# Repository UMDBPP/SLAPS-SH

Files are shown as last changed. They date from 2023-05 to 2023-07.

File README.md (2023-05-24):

# SLAPS-SH
The SLAPS Solar Harvester is intended as a the first step into solar power collection and management. While previous iterations in the SLAPS family have focused on solar panel deployment and configuration, the solar harvester focuses on collecting and managing the power generated by four solar panels. The primary device enabling this functionality is the AEM10941. This power harvesting IC collects power from the panels, regulates the power to multiple useful voltage levels, and charges a storage unit. This design required minimal passive components allowing for a low cost and space efficient design. In addition to the power harvesting circuit, the solar harvester will also feature a RP2040 microcontroller, altitude rated pressure-temperature sensor, and NAND flash for data logging. These additional components will provide an adequate test for the harvester capabilities. In order to leverage the space efficient nature of the electrical configuration, the structural construction of the solar harvester focuses on tight tolerances using 3D printed components. Maximizing the space efficiency of the solar harvester improves aesthetics and maximizes the flight line configurations that the solar harvester can fly on. Overall, this design will provide a realistic and maximally space efficient test of a solar harvesting circuit that could potentially be used in future SLAPS iterations.

## Electrical Overview
### AEM10941
The AEM10941 features multiple preset configurations as well as a custom mode. In this design, the configuration profile `111` is used by pulling the three configuration pins high. This configuration is designed for use with a Li-ion battery as the storage source and 3.3V and 1.8V outputs. The decision to use a Li-ion battery primarily comes from the need for a 3.3V output.

Quiescent current is expected to be roughly [0.6 \ \mu A](tex://0.6 \ \mu A) at a battery voltage of roughly 3.6V. The efficiency of the linear drop-out regulators are as follows:
- High-voltage: 80-90%
- Low-voltage: 70-80%

Overall, the losses experienced in the AEM10941 are relatively low in comparison to the power consumption of the device as a whole.

### RP2040
The RP2040 microcontroller is an incredibly popular Arduino compatible microcontroller with excellent design resources.

### MS560702BA03-50
The MS560702BA03-50 barometric pressure and temperature sensor designed to operate from [10](tex://10) to [1200 \ mbar](tex://1200 \ mbar) and [-40](tex://-40) to [85 \ \degree C](tex://85 \ \degree C). These values fall within typical launch conditions and this sensor should be able to provide barometric pressure and temperature values accurate to [\pm 2.5 mbar](tex://\pm 2.5 mbar) and [\pm 0.5 \ \degree C](tex://\pm 0.5 \ \degree C) for the duration of flight.

At a 3.3V supply voltage the MS560702BA03-50 has a peak power consumption of [4.62 \ mW](tex://4.62 \ mW) and a standby power consumption of [0.07 \ \mu W](tex://0.07 \ \mu W). Peak power consumption is unlikely to occur and typical power consumption at 1 sample/sec is expected to be less than [42 \ \mu W](tex://42 \ \mu W).

### Energy Storage
The solar harvester features one energy storage unit in the form of a single Li-ion battery cell.

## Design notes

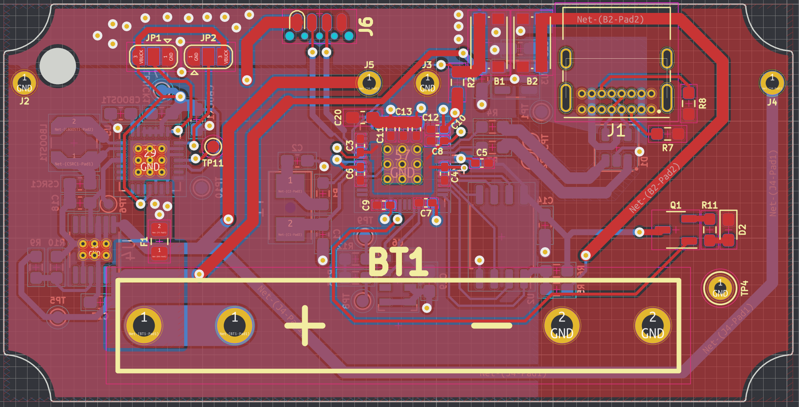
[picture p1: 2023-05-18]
Kicad/Screenshot 2023-05-16 at 6.40.45 PM.png

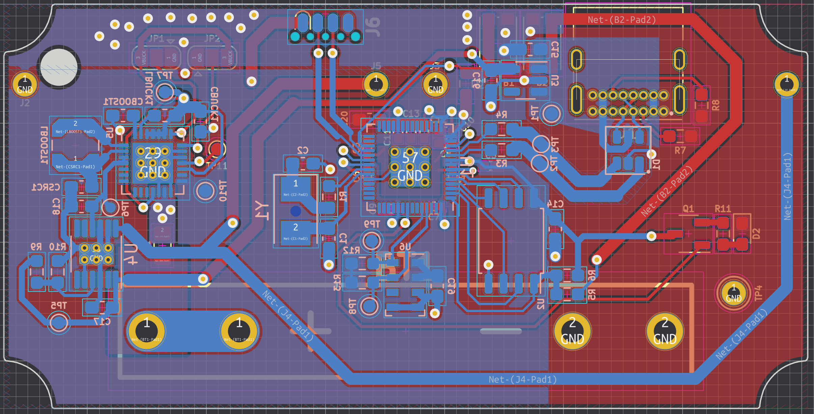
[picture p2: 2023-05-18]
Kicad/Screenshot 2023-05-16 at 6.40.51 PM.png

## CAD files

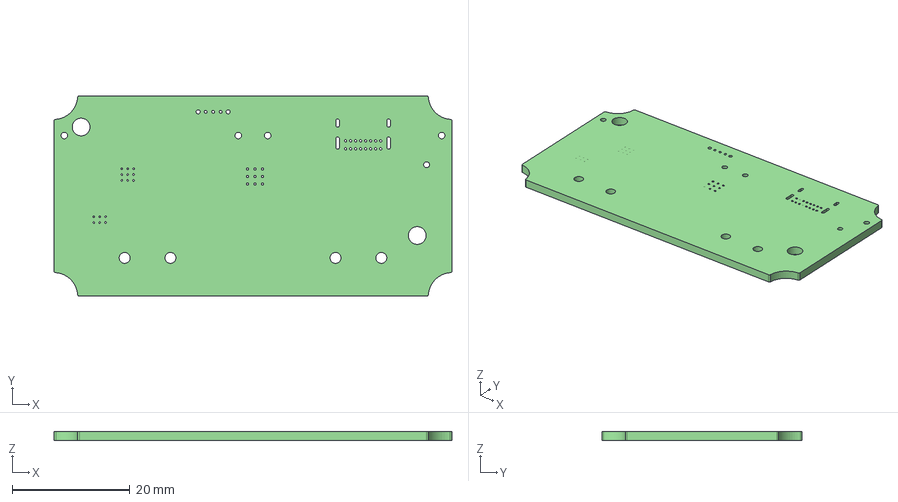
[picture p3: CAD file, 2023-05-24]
Kicad/SLAPS_Solar_Harvester/SLAPS_Solar_Harvester.step
67.5 x 34.0 x 1.60 mm

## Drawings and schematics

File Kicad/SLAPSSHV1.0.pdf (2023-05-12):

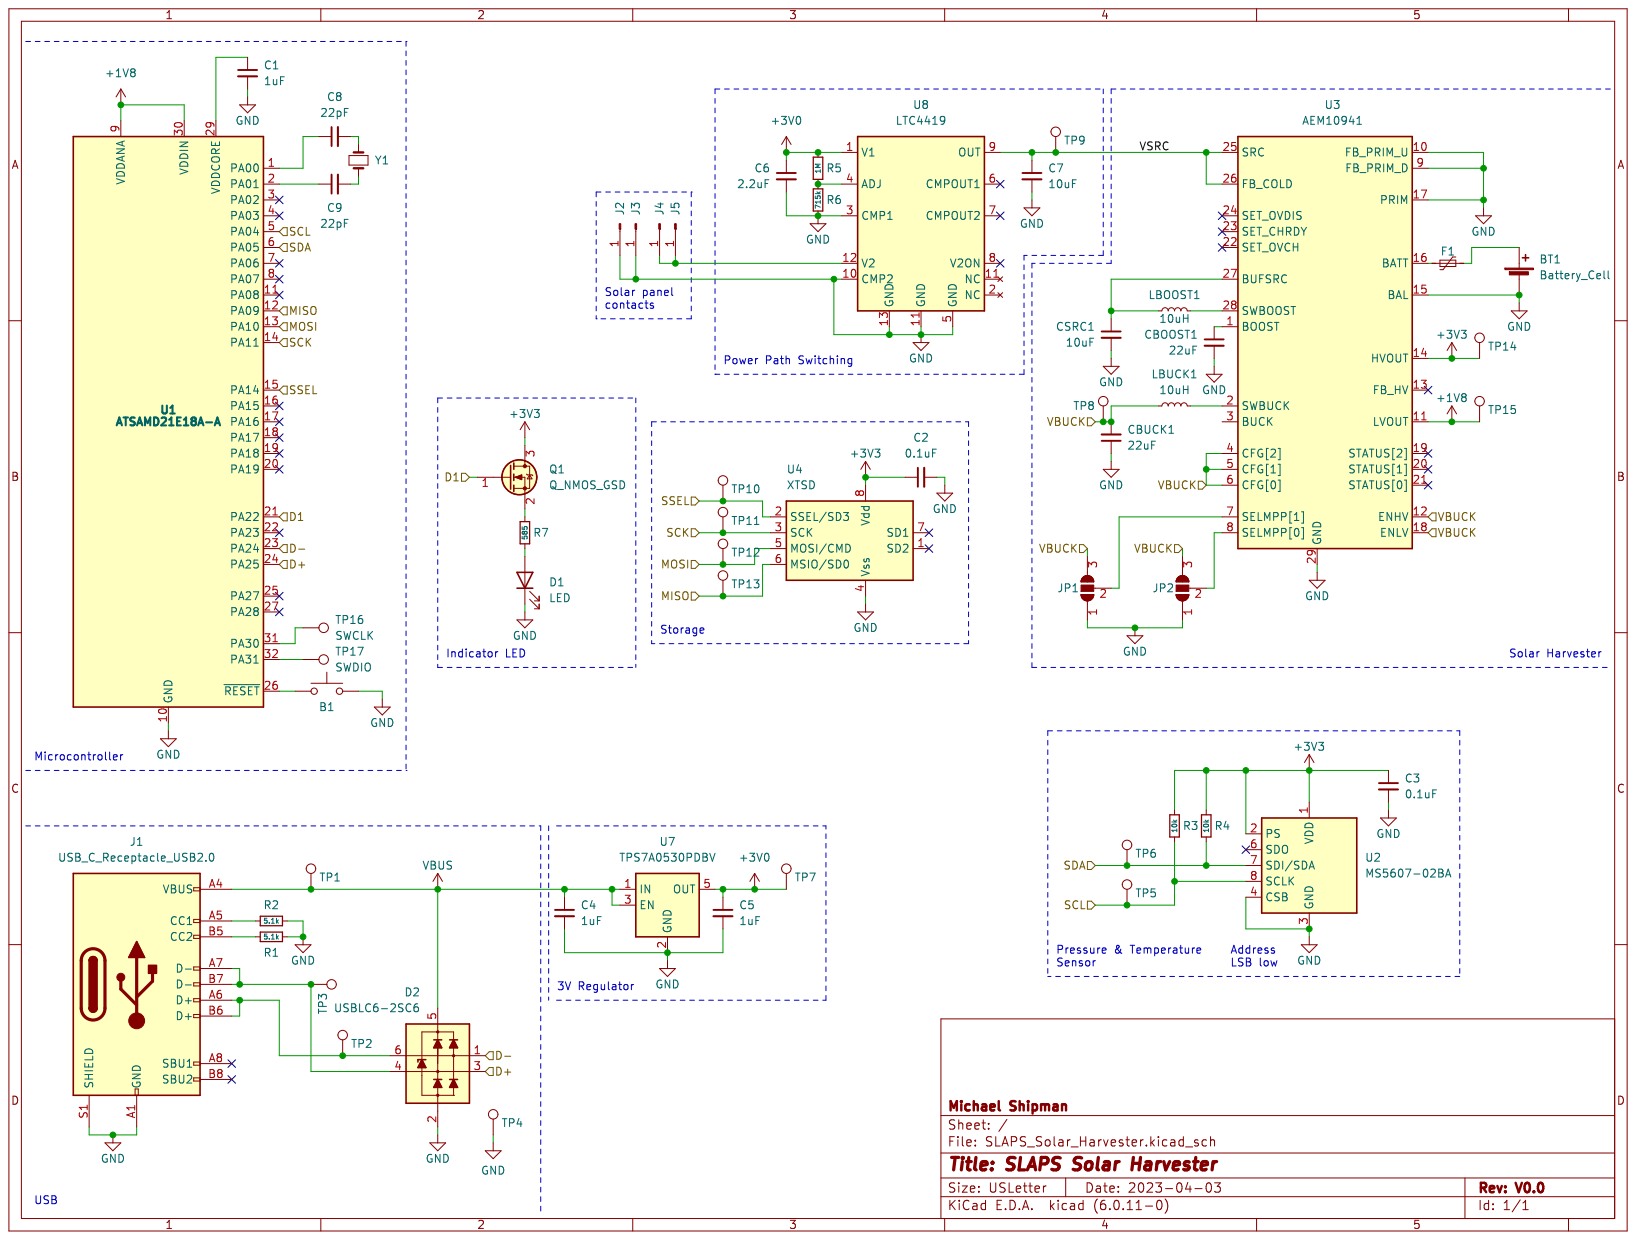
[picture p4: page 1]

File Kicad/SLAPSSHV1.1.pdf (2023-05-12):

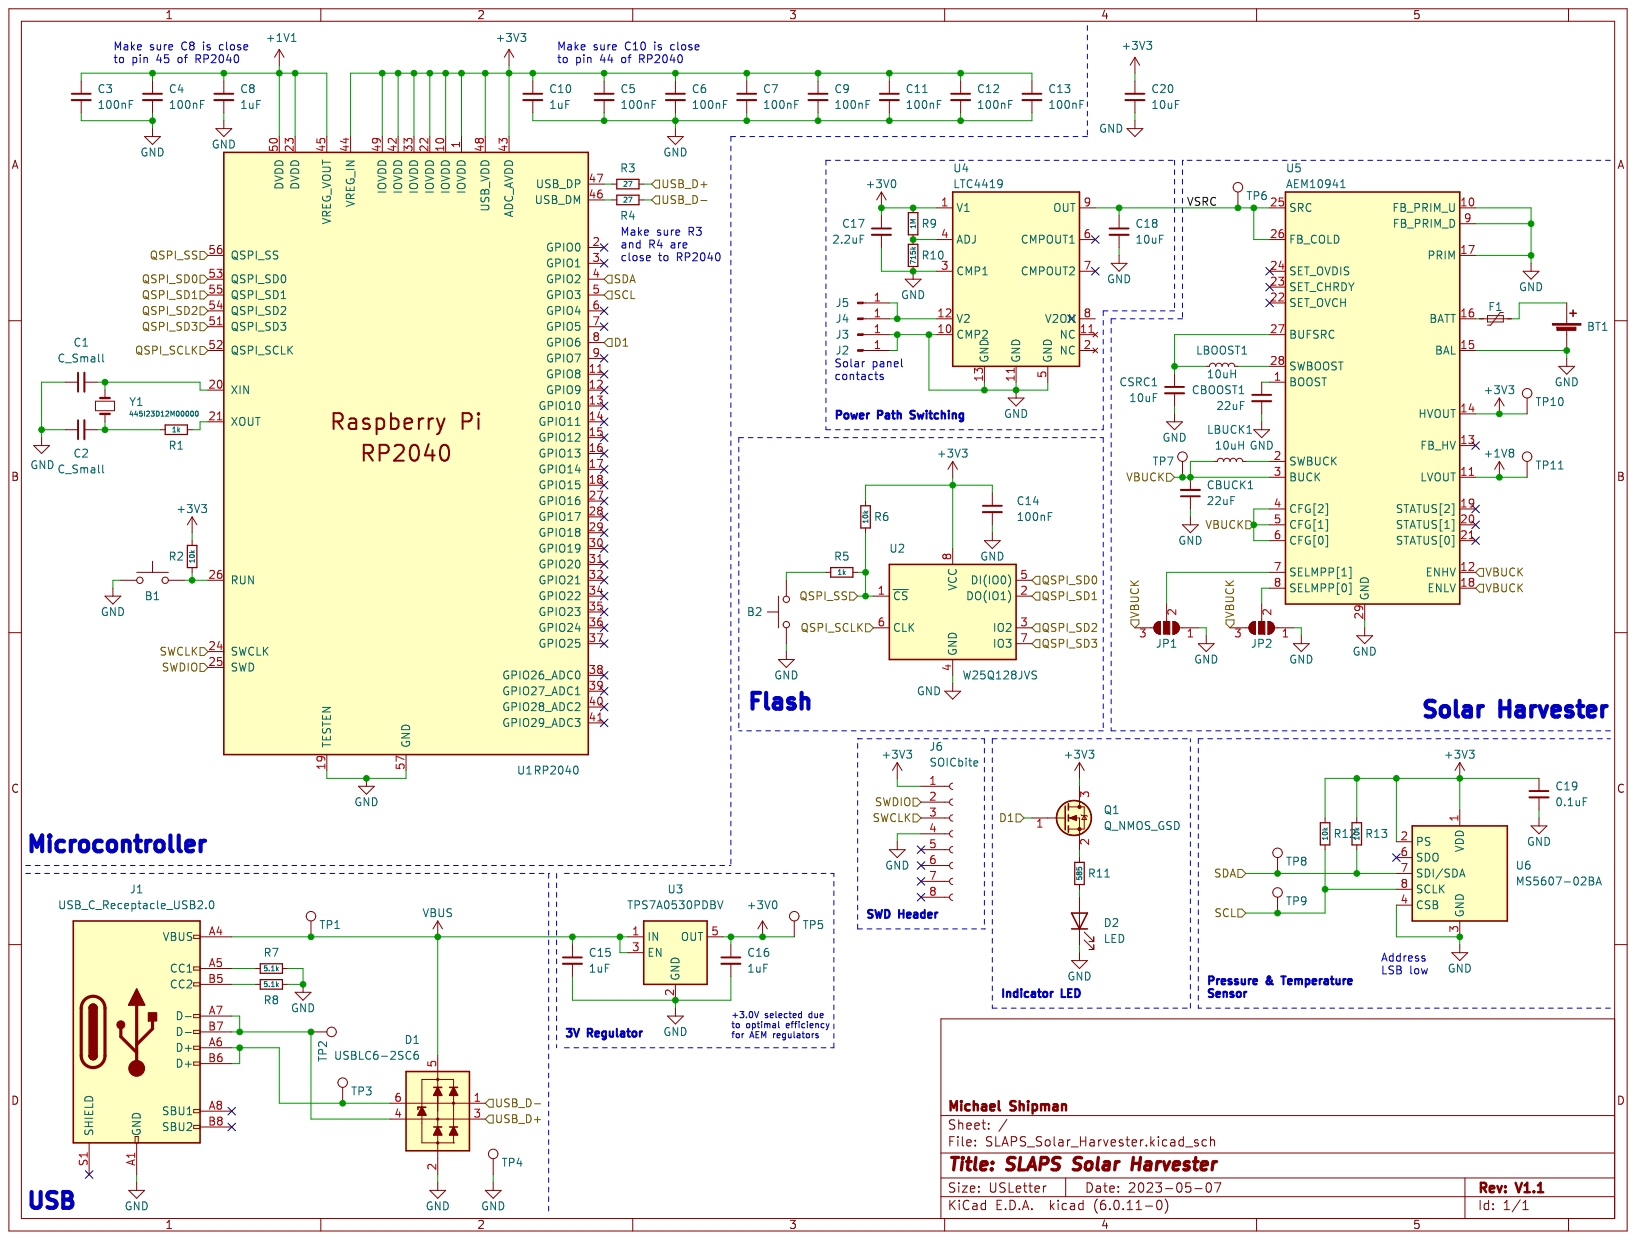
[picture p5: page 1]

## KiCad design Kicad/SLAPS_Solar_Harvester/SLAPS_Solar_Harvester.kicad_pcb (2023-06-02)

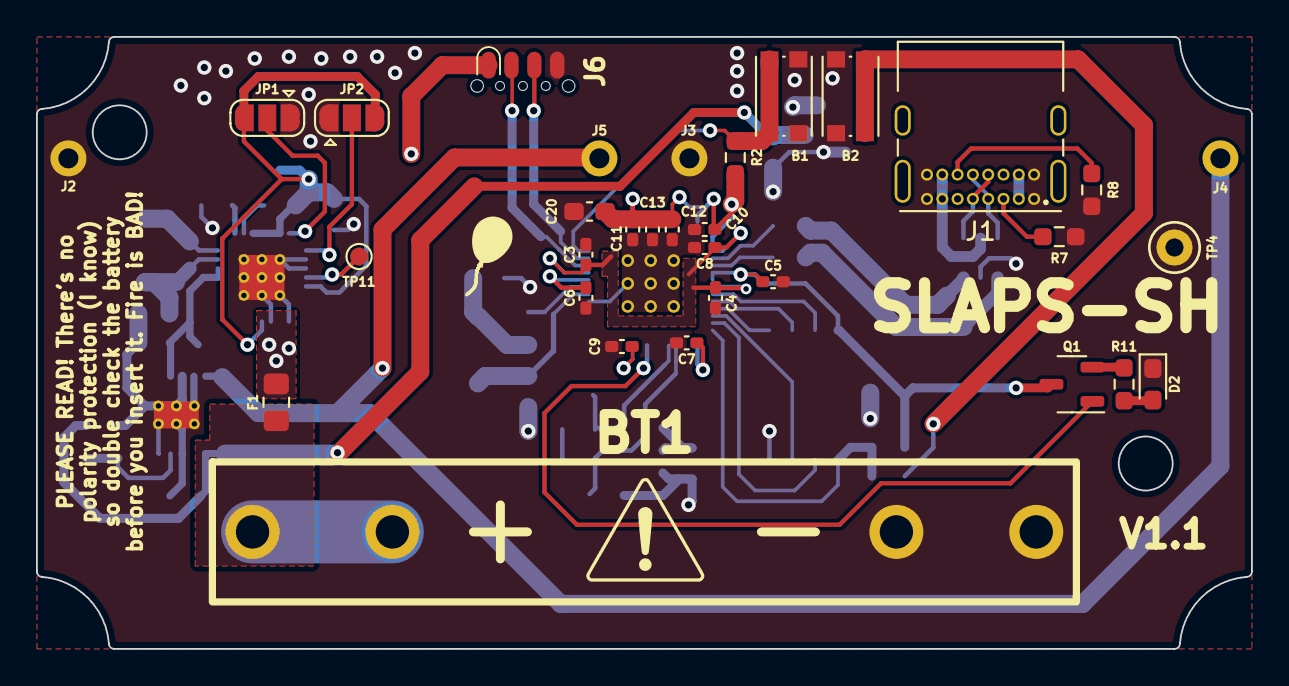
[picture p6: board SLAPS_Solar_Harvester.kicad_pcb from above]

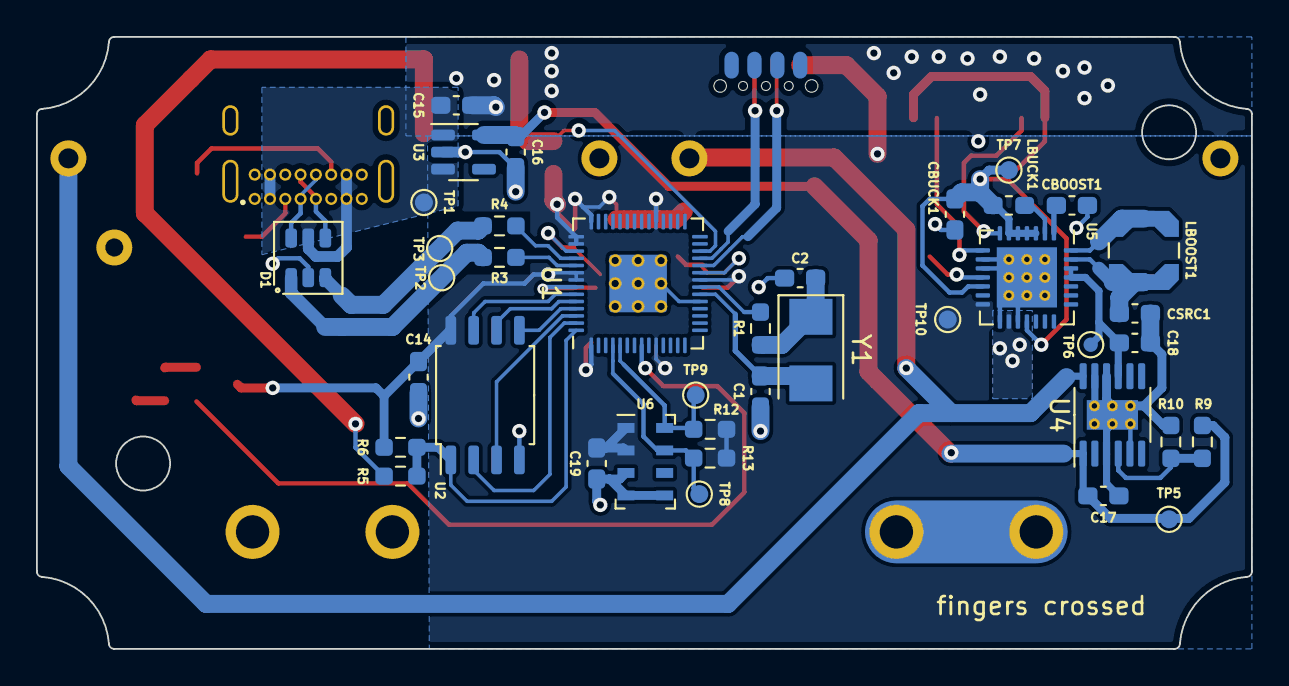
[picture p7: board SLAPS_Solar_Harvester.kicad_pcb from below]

Board: 2 copper layers, 67.5 x 34.0 mm, 71 parts (39 on the bottom side), 44 nets.

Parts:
B1, B2: KMR2; SW_Push_1P1T_NO_CK_KMR2
BT1: Battery_Cell; MPD_BK-82_x2
C1, C2: 27pF; C_0603_1608Metric_Pad1.08x0.95mm_HandSolder
C3, C4, C5, C6, C7, C9, C11, C12, C13: 100nF; C_0402_1005Metric_Pad0.74x0.62mm_HandSolder
C8, C10: 1uF; C_0402_1005Metric_Pad0.74x0.62mm_HandSolder
C14, C19: 100nF; C_0603_1608Metric_Pad1.08x0.95mm_HandSolder
C15, C16: 1uF; C_0603_1608Metric_Pad1.08x0.95mm_HandSolder
C17: 2.2uF; C_0603_1608Metric_Pad1.08x0.95mm_HandSolder
C18, C20: 10uF; C_0603_1608Metric_Pad1.08x0.95mm_HandSolder
CBOOST1: 22uF; C_0603_1608Metric_Pad1.08x0.95mm_HandSolder
CBUCK1: 22uF; C_0603_1608Metric_Pad1.08x0.95mm_HandSolder
CSRC1: 10uF; C_0603_1608Metric_Pad1.08x0.95mm_HandSolder
D1: USBLC6-2SC6; SOT-23-6
D2: LED; D_0603_1608Metric_Pad1.05x0.95mm_HandSolder
F1: Polyfuse_Small; Fuse_0805_2012Metric_Pad1.15x1.40mm_HandSolder
J1: USB_C_Receptacle_USB2.0; USB_C_Receptacle_GCT_USB4085
J2, J3, J4, J5: Conn_01x01_Male; P19-1121
J6: SOICbite; SOIC_clipProgSmall
JP1, JP2: SolderJumper_3_Open; SolderJumper-3_P1.3mm_Open_RoundedPad1.0x1.5mm
LBOOST1: 10uH; IND_LPS4012-103MRC
LBUCK1: 10uH; L_0603_1608Metric_Pad1.05x0.95mm_HandSolder
Q1: Q_NMOS_GSD; SOT-23-3
R1, R5: 1k; R_0603_1608Metric_Pad0.98x0.95mm_HandSolder
R2, R6, R12, R13: 10k; R_0603_1608Metric_Pad0.98x0.95mm_HandSolder
R3, R4: 27; R_0603_1608Metric_Pad0.98x0.95mm_HandSolder
R7, R8: 5.1k; R_0603_1608Metric_Pad0.98x0.95mm_HandSolder
R9: 1M; R_0603_1608Metric_Pad0.98x0.95mm_HandSolder
R10: 715k; R_0603_1608Metric_Pad0.98x0.95mm_HandSolder
R11: 590; R_0603_1608Metric_Pad0.98x0.95mm_HandSolder
TP1, TP2, TP3, TP5, TP6, TP7, TP8, TP9, TP10, TP11: TestPoint; TestPoint_Pad_D1.0mm
TP4: TestPoint; TestPoint_Keystone_5000-5004_Miniature
U1: RP2040; RP2040-QFN-56
U2: W25Q128JVS; SOIC-8_5.23x5.23mm_P1.27mm
U3: TPS7A0530PDBV; SOT-23-5
U4: LTC4419; MSOP-12-1EP_3x4mm_P0.65mm_EP1.65x2.85mm_ThermalVias
U5: AEM10941; QFN-28-1EP_5x5mm_P0.5mm_EP3.35x3.35mm_ThermalVias
U6: MS5607-02BA; LGA-8_3x5mm_P1.25mm
Y1: 445I23D12M00000; Crystal_SMD_5032-2Pin_5.0x3.2mm

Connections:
+1V1: C3.1, C4.1, C8.1, U1.23 (DVDD), U1.45 (VREG_VOUT), U1.50 (DVDD)
+1V8: TP11.1, U5.11 (LVOUT)
+3V0: C16.1, C17.1, R9.1, TP5.1, U3.5 (OUT), U4.1 (V1)
+3V3: C5.1, C6.1, C7.1, C9.1, C10.1, C11.1, C12.1, C13.1, C14.1, C19.1, C20.1, J6.1, Q1.3 (D), R2.1, R6.1, R12.1, R13.1, TP10.1, U1.1 (IOVDD), U1.10 (IOVDD), U1.22 (IOVDD), U1.33 (IOVDD), U1.42 (IOVDD), U1.43 (ADC_AVDD), U1.44 (VREG_IN), U1.48 (USB_VDD), U1.49 (IOVDD), U2.8 (VCC), U5.14 (HVOUT), U6.1 (VDD), U6.2 (PS)
/D1: Q1.1 (G), U1.8 (GPIO6)
/QSPI_SCLK: U1.52 (QSPI_SCLK), U2.6 (CLK)
/QSPI_SD0: U1.53 (QSPI_SD0), U2.5 (DI(IO0))
/QSPI_SD1: U1.55 (QSPI_SD1), U2.2 (DO(IO1))
/QSPI_SD2: U1.54 (QSPI_SD2), U2.3 (IO2)
/QSPI_SD3: U1.51 (QSPI_SD3), U2.7 (IO3)
/QSPI_SS: R5.2, R6.2, U1.56 (QSPI_SS), U2.1 (~CS)
/SCL: R12.2, TP9.1, U1.5 (GPIO3), U6.8 (SCLK)
/SDA: R13.2, TP8.1, U1.4 (GPIO2), U6.7 (SDI/SDA)
/SWCLK: J6.2, U1.24 (SWCLK)
/SWDIO: J6.3, U1.25 (SWD)
/USB_D+: D1.1 (L1), R3.2, TP2.1
/USB_D-: D1.3 (L2), R4.2, TP3.1
/VBUCK: CBUCK1.2, JP1.3 (B), JP2.3 (B), LBUCK1.1, TP7.1, U5.3 (BUCK), U5.4 (CFG[2]), U5.5 (CFG[1]), U5.6 (CFG[0]), U5.12 (ENHV), U5.18 (ENLV)
/VSRC: C18.1, TP6.1, U4.9 (OUT), U5.25 (SRC), U5.26 (FB_COLD)
GND: B1.1, B2.1, BT1.2 (-), C1.1, C2.1, C3.2, C4.2, C5.2, C6.2, C7.2, C8.2, C9.2, C10.2, C11.2, C12.2, C13.2, C14.2, C15.2, C16.2, C17.2, C18.2, C19.2, C20.2, CBOOST1.2, CBUCK1.1, CSRC1.2, D1.2 (VN), D2.1 (K), J1.A1 (GND), J1.A12 (GND), J1.B1 (GND), J1.B12 (GND), J2.1, J3.1, J6.4, JP1.1 (A), JP2.1 (A), R7.2, R8.2, R10.2, TP4.1, U1.19 (TESTEN), U1.57 (GND), U2.4 (GND), U3.2 (GND), U4.3 (CMP1), U4.5 (GND), U4.10 (CMP2), U4.11 (GND), U4.13 (GND), U5.9 (FB_PRIM_D), U5.10 (FB_PRIM_U), U5.15 (BAL), U5.17 (PRIM), U5.29 (GND), U6.3 (GND), U6.4 (CSB), U6.5 (CSB)
unnamed: B1.2, R2.2, U1.26 (RUN)
unnamed: B2.2, R5.1
unnamed: BT1.1 (+), F1.1
unnamed: C1.2, U1.20 (XIN), Y1.2
unnamed: C2.2, R1.1, Y1.1
unnamed: CBOOST1.1, U5.1 (BOOST)
unnamed: CSRC1.1, LBOOST1.1, U5.27 (BUFSRC)
unnamed: D1.4 (L2), J1.A7 (D-), J1.B7 (D-)
unnamed: D1.6 (L1), J1.A6 (D+), J1.B6 (D+)
unnamed: D2.2 (A), R11.2
unnamed: F1.2, U5.16 (BATT)
unnamed: J1.A5 (CC1), R7.1
unnamed: J1.B5 (CC2), R8.1
unnamed: J4.1, J5.1, U4.12 (V2)
unnamed: JP1.2 (C), U5.7 (SELMPP[1])
unnamed: JP2.2 (C), U5.8 (SELMPP[0])
unnamed: LBOOST1.2, U5.28 (SWBOOST)
unnamed: LBUCK1.2, U5.2 (SWBUCK)
unnamed: Q1.2 (S), R11.1
unnamed: R1.2, U1.21 (XOUT)
unnamed: R3.1, U1.47 (USB_DP)
unnamed: R4.1, U1.46 (USB_DM)
unnamed: R9.2, R10.1, U4.4 (ADJ)
VBUS: C15.1, D1.5 (VP), J1.A4 (VBUS), J1.A9 (VBUS), J1.B4 (VBUS), J1.B9 (VBUS), TP1.1, U3.1 (IN), U3.3 (EN)

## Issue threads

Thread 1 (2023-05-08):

Revise design for use with RP2040

michaelshipman, 2023-05-08:
After the troubles with V1.0 I think it may be prudent to move the design to the RP2040 for a couple of reasons.

- Honestly I want to
- I like Raspberry Pi's materials more
- I'd like to use the RP2040 in more designs so I might as well start

Now that the lab has acquired a proper hotplate and I have a little practice with QFN packages I'm reasonably certain I can land this part. The SAMD21's easily hand-solderable package selection was a major part of it's selection for V1.0

michaelshipman, 2023-05-08:
It should be noted that the change to the RP2040 will remove the need for the XTSD flash storage since the QSPI program flash used should be plenty for the simple pressure and temperature logging being performed by the payload. The RP2040 also supports exposing this flash as a mass storage device and should be able to achieve complete feature parity with the SAMD21 for this application.

michaelshipman, 2023-05-18:
I did it, was pretty easy, hopefully it works.

Closed 2023-05-18.

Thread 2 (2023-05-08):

AEM10941 Regulator Noise

michaelshipman, 2023-05-08:
Significant noise was observed on the 1.8V power rail coming from the AEM10941 low-voltage regulator. Although V1.0 lacked decoupling capacitors on this rail a 1uF and 0.1uF capacitor were bodged on and significant electrical noise of about 300 mV was still observed.

I'd like to review the datasheet for this part and see if any layout guidelines need to be actioned on.

michaelshipman, 2023-05-18:
Well there's a lot of decoupling on the RP2040 design, and I'm not even using the 1.8V regulator for V1.1.

Closed 2023-05-18.

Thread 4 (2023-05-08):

Fix the footprint for LBOOST1

michaelshipman, 2023-05-08:
Unbeknownst to me you have to actually specify in the footprint that you do not want solder mask covering pads! While scraping off the solder mask may have temporarily scratched my lotto itch I'd rather not repeat the experience.

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

Closed 2023-05-16.

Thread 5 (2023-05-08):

Fix fuse footprint

michaelshipman, 2023-05-08:
I must have been intending on using a 1210 fuse at some point and then switched to 0805. Not really an issue but it looks silly.

Closed 2023-05-16.

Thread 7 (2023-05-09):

Swapped D+ and D-

michaelshipman, 2023-05-09:
While redesigning for V1.1 I noticed that the D+ and D- lines are swapped through the TVS diode. This likely a primary source of the woes I experienced with V1.0. I'm going to test it at some point and see if that resolves some of my issues.

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

Closed 2023-05-16.

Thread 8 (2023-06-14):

Crystal Not Oscillating

michaelshipman, 2023-06-14:
First attempt at V1.1 bring up unsuccessful, when probing oscillator no signal was observed.

Next steps: will try to tune load capacitors and try replacing the crystal.

michaelshipman, 2023-06-23:
- Replaced crystal
- Changed load capacitors to 22pF
- Removed series resistor

Crystal now oscillates properly and board can be programmed

Closed 2023-06-23.

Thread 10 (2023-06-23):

Significant Voltage Drop on +3.0V Rail

michaelshipman, 2023-06-23:
I think this just needs some additional tankage (10uF) on the +3.0V rail and probably the +3.3V rail too.

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

michaelshipman, 2023-06-24:
Added additional tankage in the form of a 10uF capacitor on the +3.0V rail, no significant improvement observed.

michaelshipman, 2023-07-01:
Yeah I should just add a filter.

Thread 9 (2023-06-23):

Buzzing Observed During Operation

michaelshipman, 2023-06-23:

michaelshipman, 2023-06-23:
I'm thinking it's the crystal, just had the second crystal on this board go, unsure of the cause but after it stopped oscillating the noise was gone. Replaced new crystal and added 1k resistor back and the device seems to operate normally again. Can still hear the crystal it's just quieter I think.

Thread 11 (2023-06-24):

Pressure Temperature Sensor Accuracy

michaelshipman, 2023-06-24:
First read of the pressure temperature sensor using the below library read:
- 30-31 °C
- ~30 m
- ~1009 mBar

The pressure actually seems to be fair accurate, the lab was pretty warm when I read these values but I don't think it was almost 90 °F, the altitude also seems off but I'm not sure how accurate I can expect it to be.

michaelshipman, 2023-07-01:
I think it may actually be fairly accurate, I pointed the thermal camera at it and the sensor appeared to be at a temperature very similar to the values being read by the RP2040.

Closed 2023-07-01.

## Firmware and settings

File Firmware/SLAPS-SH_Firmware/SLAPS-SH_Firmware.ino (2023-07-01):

#include "src/MS5607SLAPS.h"
#include <SingleFileDrive.h>
#include <LittleFS.h>

uint32_t cnt = 0;
bool okayToWrite = true;
MS5607 P_Sens;
float P_val,T_val,H_val;

// Make the CSV file and give it a simple header
void headerCSV() {
  File f = LittleFS.open("data.csv", "w");
  f.printf("sample,millis,temp,pressure,alt\n");
  f.close();
  cnt = 0;
}

// Called when the USB stick connected to a PC and the drive opened
// Note this is from a USB IRQ so no printing to SerialUSB/etc.
void plug(uint32_t i) {
  (void) i;
  okayToWrite = false;
}

// Called when the USB is ejected or removed from a PC
// Note this is from a USB IRQ so no printing to SerialUSB/etc.
void unplug(uint32_t i) {
  (void) i;
  okayToWrite = true;
}

// Called when the PC tries to delete the single file
// Note this is from a USB IRQ so no printing to SerialUSB/etc.
void deleteCSV(uint32_t i) {
  (void) i;
  LittleFS.remove("data.csv");
  headerCSV();
}

void setup(void){

  LittleFS.begin();

  // Set up the USB disk share
  singleFileDrive.onDelete(deleteCSV);
  singleFileDrive.onPlug(plug);
  singleFileDrive.onUnplug(unplug);
  singleFileDrive.begin("data.csv", "data.csv");

  // Find the last written data
  File f = LittleFS.open("data.csv", "r");
  if (!f || !f.size()) {
    cnt = 1;
    headerCSV();
  } else {
    if (f.size() > 2048) {
      f.seek(f.size() - 1024);
    }
    do {
      String s = f.readStringUntil('\n');
      sscanf(s.c_str(), "%lu,", &cnt);
    } while (f.available());
    f.close();
    cnt++;
  }

  P_Sens.begin();
}

void loop(void){
  if (P_Sens.readDigitalValue()) {
    T_val = P_Sens.getTemperature();
    P_val = P_Sens.getPressure();
    H_val = P_Sens.getAltitude();

    // Make sure the USB connect doesn't happen while we're writing!
    noInterrupts();
    if (okayToWrite) {
      Serial.printf("Sampling...%lu\n", cnt);
      // Don't want the USB to connect during an update!
      File f = LittleFS.open("data.csv", "a");
      if (f) {
        f.printf("%lu,%lu,%f,%f,%f\n", cnt++, millis(), T_val, P_val, H_val);
        f.close();
      }
    }
    interrupts();
  }
  
  

  delay(1000);
}

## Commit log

2023-05-08 started on V1.1
    [SLAPS_Solar_Harvester.kicad_sch]
2023-05-09 working on RP2040 rev
    [SLAPS_Solar_Harvester.kicad_pcb, SLAPS_Solar_Harvester.kicad_sch]
2023-05-12 some extras
    [SLAPS_Solar_Harvester.kicad_pcb, SLAPS_Solar_Harvester.kicad_sch, SLAPS_Solar_Harvester.step]
2023-05-16 more work on V1.1
    [SLAPS_Solar_Harvester.kicad_pcb, SLAPS_Solar_Harvester.kicad_sch]
2023-05-18 more V1.1
    [SLAPS_Solar_Harvester-B_Cu.gbr, SLAPS_Solar_Harvester-B_Mask.gbr, SLAPS_Solar_Harvester-B_Paste.gbr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]
2023-05-24 step file of board
    [SLAPS_Solar_Harvester.step]
2023-06-02 KiCad version 7
    [SLAPS_Solar_Harvester.kicad_pcb, SLAPS_Solar_Harvester.kicad_sch]
2023-07-01 Minimal firmware
    [SLAPS_Solar_Harvester.kicad_sch]
2023-11-27 added reference pdf
    [SLAPS_Solar_Harvester-B_Cu.gbl, SLAPS_Solar_Harvester-B_Mask.gbs, SLAPS_Solar_Harvester-B_Paste.gbp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]
